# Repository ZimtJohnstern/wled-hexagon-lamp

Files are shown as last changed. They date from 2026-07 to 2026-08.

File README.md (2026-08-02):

# WLED Hexagon Project

*[Deutsche Version](README.de.md)*

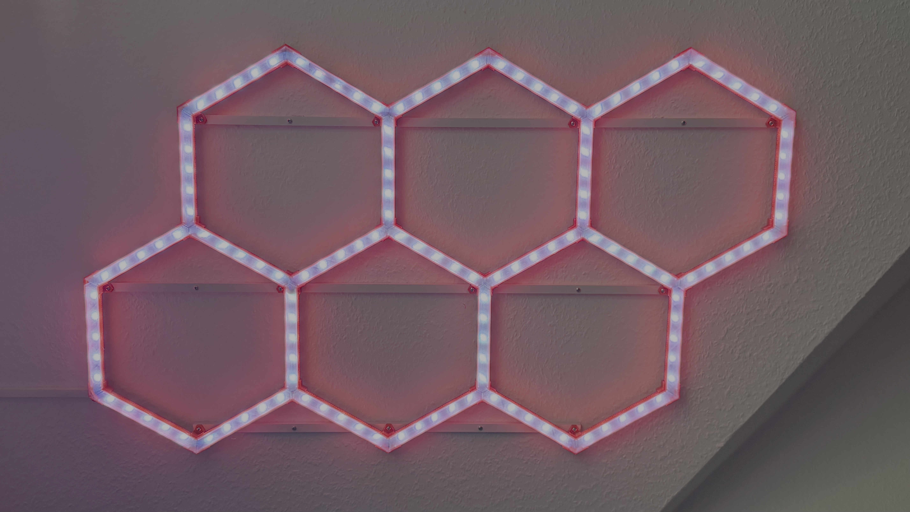
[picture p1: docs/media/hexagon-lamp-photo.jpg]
Finished lamp


6 clip-together LED hexagons (frame design: [Hexagon LED Lamp by NickiDotDK, Printables](https://www.printables.com/model/1063657), CC BY-NC 4.0), driven by WLED on an ESP32 with WS2801 strips and a custom PCB.

**→ Full build guide including video: [BUILD_GUIDE.md](BUILD_GUIDE.md)**

## Hardware overview

| Component | Value/Type |
|---|---|
| MCU | ESP32-WROOM-32, 30-pin devboard |
| LEDs | WS2801, 135 LEDs total, 6 hexagons |
| Power supply | 5 V / 10 A |
| Level buffer | IC1: SN74AHCT125N |
| Data pin (ESP32) | GPIO 23 |
| Clock pin (ESP32) | GPIO 18 |

Details, BOM and wiring: [`docs/hardware.md`](docs/hardware.md) · WLED configuration: [`docs/wled-config.md`](docs/wled-config.md)

*(Note: `docs/hardware.md` and `docs/wled-config.md` are currently German-only. Ask/open an issue if you'd like an English translation.)*

## Repo structure

```
WLED_Hexagone_Project/
├── README.md / README.de.md
├── BUILD_GUIDE.md / BUILD_GUIDE.de.md
├── LICENSE.md                   # CC BY-NC-SA 4.0 for board/enclosure/firmware config
├── .gitignore
├── docs/
│   ├── hardware.md              # BOM, pinout, wiring (German)
│   ├── wled-config.md           # WLED setup, verified config values, LED mapping (German)
│   └── media/
│       ├── hexagon-lamp-photo.jpg
│       ├── clip.mov
│       └── ledmap-reference-jakepeters.png
├── hardware/
│   ├── pcb/
│   │   ├── schaltplan.pdf       # schematic
│   │   ├── ESP32_WLED_WS2801.step
│   │   ├── BOM.txt
│   │   └── CAMOutputs/           # Gerber, drill, assembly (manufacturing data)
│   └── enclosure/
│       ├── WLED_Case_5V10A_ESP32.step
│       ├── Top.3mf / Bottom.3mf / Clamp_in.3mf / Clamp_out.3mf
│       └── Top.stl / Bottom.stl / Clamp_in.stl / Clamp_out.stl
├── model-source/
│   ├── LICENSE-model.md         # CC BY-NC 4.0 notice for the hexagon STL/STEP model
│   └── hexagon-led-lamp.pdf     # Original Printables product page export
├── printables/                  # Printables.com submission package
└── firmware/
    ├── ledmap.json
    ├── wled_cfg_WLED.json
    └── wled_presets_WLED.json
```

## WLED fork

This project uses a fork of [wled/WLED](https://github.com/wled/WLED) (official upstream, MIT license). Include the fork as a **git submodule** or a **separate repo** — see [`docs/wled-config.md`](docs/wled-config.md) for the recommended command.

## License

- Hexagon 3D model: [NickiDotDK](https://www.printables.com/model/1063657), CC BY-NC 4.0 — see `model-source/LICENSE-model.md`
- PCB, enclosure, firmware configuration of this project: **CC BY-NC-SA 4.0** — see [`LICENSE.md`](LICENSE.md). Commercial resale of replicas is not permitted; private builds and non-commercial sharing with attribution are welcome.

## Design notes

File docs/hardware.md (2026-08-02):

# Hardware

## Stückliste (BOM)

Quelle: Export aus Fusion Electronics/EAGLE, Projekt `ESP32_WLED_WS2801` (`hardware/pcb/BOM.txt`).
## Stückliste / Bill of Materials (BOM)

Die folgende Tabelle listet die verwendeten Elektronikkomponenten für das Projekt auf. Die Links führen direkt zu den von mir verwendeten Artikeln auf AliExpress:

| Ref | Bauteil | Menge | Wert / Typ | Package / Info | Link |
| :--- | :--- | :---: | :--- | :--- | :--- |
| **—** | **Microcontroller** | 1 | ESP32 DevBoard | 30-Pin Version | [Auf AliExpress ansehen](https://s.click.aliexpress.com/e/_c32ZkRiR)* |
| **—** | **LED-Streifen** | 1 | WS2801 (5 Meter) | Digital steuerbarer LED-Strip (Data & CLK) | [Auf AliExpress ansehen](https://s.click.aliexpress.com/e/_c3UGIH2X)* |
| **IC1** | **Quad-Bus-Buffer** | 1 | SN74AHCT125N | DIL14 (Pegelwandler für Datensignal) | [Auf AliExpress ansehen](https://s.click.aliexpress.com/e/_c4MjYV6J)* |
| **F1** | **Sicherungshalter** | 1 | 250 V / 10 A | Keystone 4527 / Inkl. Sicherung | [Auf AliExpress ansehen](https://s.click.aliexpress.com/e/_c4r8BMD1)* |
| **C1, C2** | **Elko (Kondensator)** | 2 | 470 µF | CAPPRD200W80D500H1100B (Aus Kit) | [Auf AliExpress ansehen](https://s.click.aliexpress.com/e/_c39kk2Jl)* |
| **C3** | **Kondensator** | 1 | 100 nF | C050-025X075 (Aus Metallkondensator-Kit) | [Auf AliExpress ansehen](https://s.click.aliexpress.com/e/_c3iZH0cB)* |
| **R1, R2** | **Widerstand** | 2 | 100 Ω | 0207/10 | [Auf AliExpress ansehen](https://s.click.aliexpress.com/e/_c3YJjZPD)* |
| **U$1** | **Klemmleiste 2-polig** | 1 | 2828XX-2282837-2 | Stromversorgung In: V+ / V- vom Netzteil | [Auf AliExpress ansehen](https://s.click.aliexpress.com/e/_c3zC1WLl)* |
| **U$2** | **Klemmleiste 4-polig** | 1 | 2828XX-4282837-4 | Ausgang zu WS2801: V+, Data, CLK, V- | [Auf AliExpress ansehen](https://s.click.aliexpress.com/e/_c3zC1WLl)* |
| **—** | **Netzteil** | 1 | 5V / 10A | Stromversorgung für das Gesamtsystem | [Auf AliExpress ansehen](https://s.click.aliexpress.com/e/_c4Lgpqx9)* |
| **-** | Filament | — | Kingroon PETG (für das Gehäuse) | Grau / Wunschfarbe | [Auf AliExpress ansehen](https://s.click.aliexpress.com/e/_c3n4955V)* |
---

### 📢 Transparenzhinweis & Support
Die mit einem Sternchen (`*`) gekennzeichneten Produktlinks sind sogenannte **Affiliate-Links**. Wenn du über diese Links auf AliExpress einkaufst, erhalte ich eine kleine Provision vom Händler. Für dich entstehen dabei **absolut keine Mehrkosten**. Du unterstützt damit direkt die Weiterentwicklung und Pflege dieses Open-Source-Projekts. Vielen Dank!

## Pinbelegung ESP32

| Funktion | GPIO |
|---|---|
| WS2801 Data | 23 |
| WS2801 Clock | 18 |

## Verdrahtungshinweise

**Projektspezifisch (verifiziert):** U$2 liefert V+ (5V), Data und CLK für den WS2801-Strip. Beim Verdrahten der 6 Hexagone gilt: **Anfangspunkt und Endpunkt der Kette müssen beide mit 5V gespeist werden**, um Spannungsabfall über die gesamte Kette zu vermeiden — nicht nur am Anfang einspeisen.

**Zum Vergleich, Original-Community-Modell (NickiDotDK, andere Spannungslage):** Dessen Bauanleitung nutzt 12V-LED-Strips (nicht adressierbar, kein WS2801) und empfiehlt dort, bei 4 Hexagonen 3 einzelne Strips separat mit Strom zu speisen ("power infuse"). Das ist ein anderer LED-Typ mit anderer Spannung als in diesem Projekt (WS2801, 5V) — als Hintergrund erwähnt, aber nicht direkt auf dieses Setup übertragbar.

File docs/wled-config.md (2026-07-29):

# WLED-Setup

## Fork einbinden

Zwei Optionen, je nachdem ob ihr eigenen Code in WLED ändern wollt oder nur konfiguriert:

**Option A — WLED als git submodule (empfohlen, wenn ihr WLED-Quellcode selbst anpasst):**
```bash
cd WLED_Hexagone_Project
git submodule add https://github.com/<euer-fork>/WLED.git firmware/WLED
git commit -m "Add WLED fork as submodule"
```

**Option B — nur Verweis/Fork-Link im Doc, kein Submodule** (ausreichend, wenn ihr WLED nur über die Web-UI konfiguriert, ohne Quellcode-Änderungen).

## Verifizierte Hardware-Konfiguration

Aus `firmware/wled_cfg_WLED.json` (Gerätename: `WLED_Buero`), Werte gegen den WLED-Quellcode (`wled00/const.h`) geprüft:

| Feld | Wert | Bedeutung |
|---|---|---|
| `type` | 50 | `TYPE_WS2801` — bestätigt korrekt |
| `pin` | [23, 18] | Data = GPIO 23, Clock = GPIO 18 |
| `order` | 2 | `COL_ORDER_BRG` — Farbkanalreihenfolge Blau-Rot-Grün |
| `total` | 135 | Gesamtzahl LEDs (nicht 180 — siehe Korrektur unten) |
| `ledma` | 60 | max. mA-Limit pro LED (60mA) |
| `maxpwr` | 8000 | Strombegrenzung gesamt: 8000 mA |
| `fps` | 42 | |

**Korrektur ggü. erster Schätzung:** 135 LEDs gesamt, nicht 6×6×5=180. Aus den Presets ersichtlich: Segment "Aussen" = 90 LEDs (Index 0–90), Segment "Innen" = 45 LEDs (Index 90–135). Bei der Honeycomb-Anordnung (gemeinsame Kanten zwischen benachbarten Hexagonen) ist die tatsächliche Seitenzahl niedriger als bei 6 vollständig getrennten Hexagonen.

## LED-Mapping

`firmware/ledmap.json` enthält die physische Pixel-Reihenfolge (`map`-Array, 135 Einträge, Index 0–134) — vermutlich zur Kompensation der Verkabelungsreihenfolge, damit Segmente/Effekte in der WLED-UI der visuellen Anordnung der Hexagone entsprechen statt der physischen Kabelreihenfolge.

`docs/media/ledmap-reference-jakepeters.png` ist ein Referenzdiagramm mit LED-Nummerierung von **Jake Peters** ("WLED Hexagon Lamp", eigenständiges Projekt/Community-Referenz) — das ist **nicht** derselbe Urheber wie das physische Hexagon-Modell (NickiDotDK, siehe `model-source/`). Beide Namen sollten in der Doku nicht vermischt werden, falls ihr das Repo veröffentlicht: NickiDotDK = 3D-Modell (CC BY-NC 4.0), Jake Peters = LED-Mapping-Referenz (Lizenz unbekannt, hier nicht mitgeliefert, nur als eigenes Foto/Screenshot referenziert).

## Presets

`firmware/wled_presets_WLED.json` enthält 9 gespeicherte Presets (Solid, Chase, Aurora, Candle Multi, Lake, Plasma, Rocktaves, Shimmer, Tetrix), jeweils mit eigenen Effekt-/Palette-Einstellungen pro Segment (Aussen/Innen getrennt ansteuerbar).

## Hardware-Konfiguration in der WLED-Web-UI (zum Nachvollziehen/Neuaufsetzen)

1. Config → LED Preferences
2. LED-Typ: **WS2801 (SPI)**
3. Data-Pin: **23**, Clock-Pin: **18**
4. Farbreihenfolge: **BRG**
5. Anzahl LEDs: **135**
6. Segmente: "Aussen" (0–90), "Innen" (90–135) — siehe Presets für exakte Werte

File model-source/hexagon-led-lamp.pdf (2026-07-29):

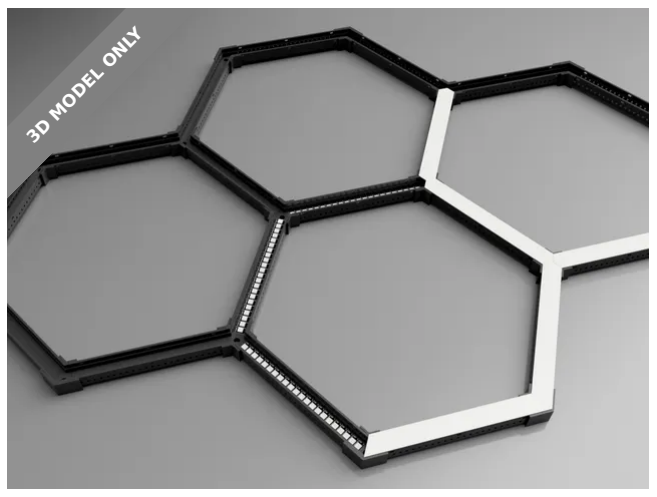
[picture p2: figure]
3D MODEL ONLY

## Summary

Click together hexagon LED lamp.

Household (https://printables.com/model?categoryId=3) > Home Decor (https://printables.com/model?categoryId=44)

Tags: | hexagon | light | lamp | led | ledlight | ledlamp
hexagonled

Click together hexagon LED lamp. Perfect for garage, homegym, workshop or similar. There is room for wiring underneath the individual segments and holes in the corner pieces to feed the wires to the led strips.

I am using 12v natural white led strips from ali with 1200 leds per 5 meters https://www.aliexpress.com/item/1005002355317307.html?spm=a2g0o.order_list.order_list_main.5.7f2279d2mBYwmp (https://www.aliexpress.com/item/1005002355317307.html)

The led strips are pretty bright but could have been a bit brighter imo.

if anyone know of some good high lumen 12v led strips, please feel free to dm me!

I am using 10x2mm flat aluminum profiles as heatsinks underneath the led strips.

NickiDotDK (https://printables.com/@NickiDotDK_1790933)

## Hexagon LED Lamp

VIEW IN BROWSER (https://printables.com/model/1063657-hexagon-led-lamp)

updated 11. 3. 2025 | published 11. 3. 2025

## Model files

Make sure to either power infuse or run wires that power a limited amount of hexagons. For 4 heagons I run power for 3 individual strips.

I have printed the rails and corners in PLA and the diffusers in PETG.

No support needed.

Infill 15%.

rail-straight.stl

double-joint-with-screw-fixture.stl

tripple-joint-with-screw-fixture.stl

tripple-joint.stl

double-joint.stl

double-joint-with-wire-entry.stl

diffuser-straight-triple-double-right.stl

## License

This work is licensed under a
Creative Commons (4.0 International License)

Attribution-NonCommercial (http://creativecommons.org/licenses/by-nc/4.0/)

✖ | Sharing without ATTRIBUTION
✔ | Remix Culture allowed
✖ | Commercial Use
✖ | Free Cultural Works
✖ | Meets Open Definition

diffuser-straight-tripple-tripple.stl

diffuser-straight-triple-double-left.stl

diffuser-straight-double-double.stl

hexagonled.step

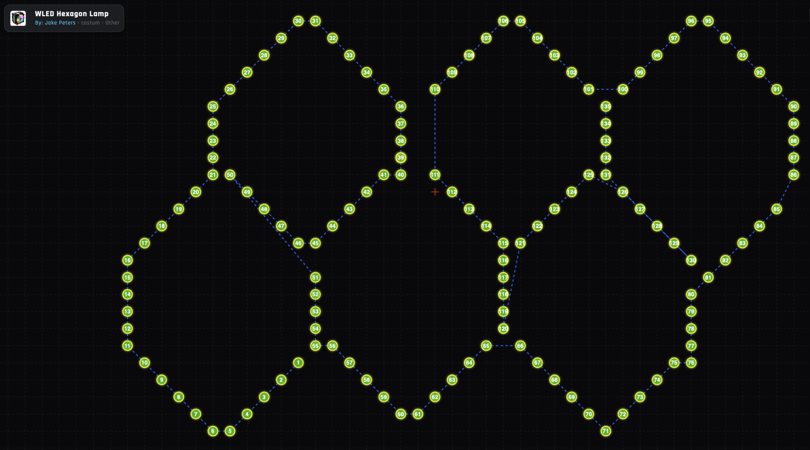
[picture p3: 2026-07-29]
docs/media/ledmap-reference-jakepeters.png

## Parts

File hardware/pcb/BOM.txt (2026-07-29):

Partlist exported from ESP32_WLED_WS2801

Reference Designators Quantity Description                                                   Package                Value            Manufacturer                    Manufacturer Part Number Vendor Vendor Part Number Top/Bottom 
                      1        Board                                                         Board                                                                                                                                 
C1, C2                2        Capacitor Polarised - Generic                                 CAPPRD200W80D500H1100B 470µF                                                                                              Top        
C3                    1        CAPACITOR, European symbol                                    C050-025X075           100nF                                                                                               Top        
F1                    1        FUSE HLDR CARTRIDGE 250V 5A PCB                               4527                   4527             Keystone Electronics            4527                                               Top        
IC1                   1        Quad bus BUFFER, 3-state                                      DIL14                  74125N                                                                                              Top        
JP1, JP2              2        Pin Header                                                    1X15                   PINHD-1X15                                                                                          Top        
R1, R2                2        RESISTOR, European symbol                                     0207/10                100                                                                                                 Top        
U$1                   1        2 Position Wire to Board Terminal Block Horizontal with Board TERMBLK_508-2N         2828XX-2282837-2 TE Connectivity AMP Connectors  282837-2                                           Top        
U$2                   1        4 Position Wire to Board Terminal Block Horizontal with Board TERMBLK_508-4N         2828XX-4282837-4 TE Connectivity AMP Connectors  282837-4                                           Top

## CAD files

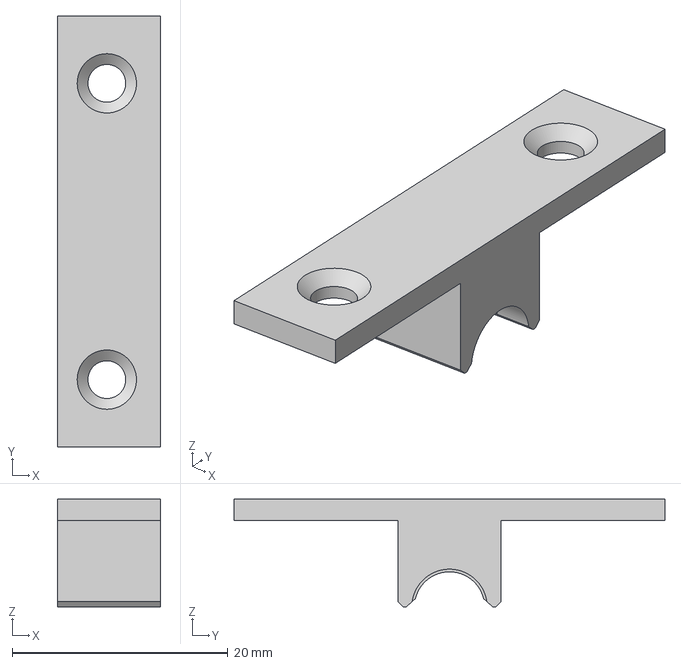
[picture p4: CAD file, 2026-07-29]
hardware/enclosure/Clamp_out.3mf
9.60 x 40.0 x 10.0 mm

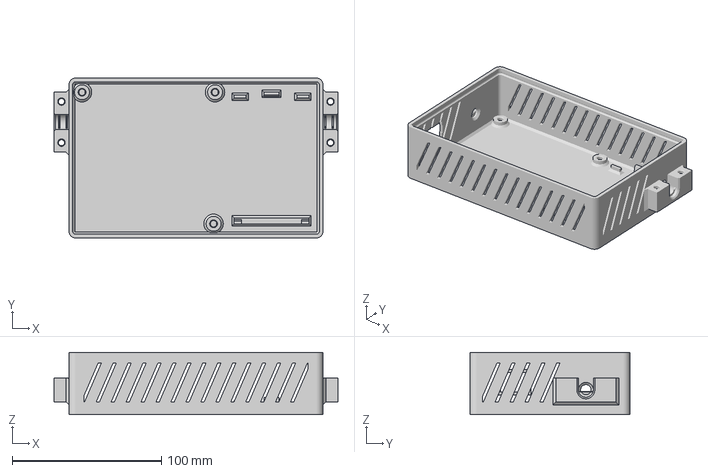
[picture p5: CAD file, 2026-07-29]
printables/Bottom.3mf
190.0 x 107.0 x 41.5 mm

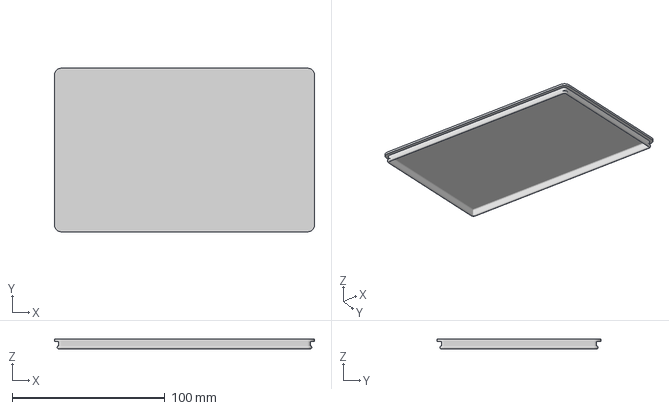
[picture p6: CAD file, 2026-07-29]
hardware/enclosure/Top.3mf
170.0 x 107.0 x 6.50 mm

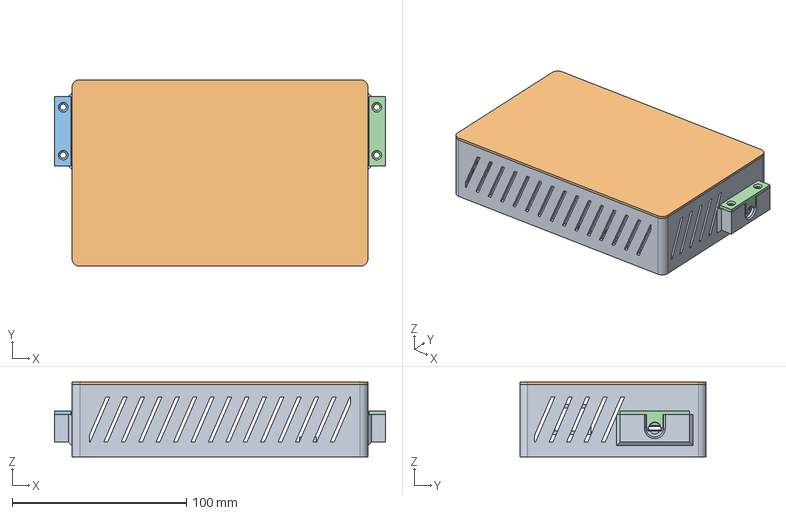
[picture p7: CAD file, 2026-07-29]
hardware/enclosure/WLED_Case_5V10A_ESP32.step
190.0 x 107.0 x 43.0 mm

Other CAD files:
hardware/enclosure/Clamp_in.3mf
printables/Clamp_in.3mf
hardware/enclosure/Bottom.stl
hardware/enclosure/Clamp_in.stl
hardware/enclosure/Clamp_out.stl
hardware/enclosure/Top.stl
printables/Bottom.stl
printables/Clamp_in.stl
printables/Clamp_out.stl
printables/Top.stl

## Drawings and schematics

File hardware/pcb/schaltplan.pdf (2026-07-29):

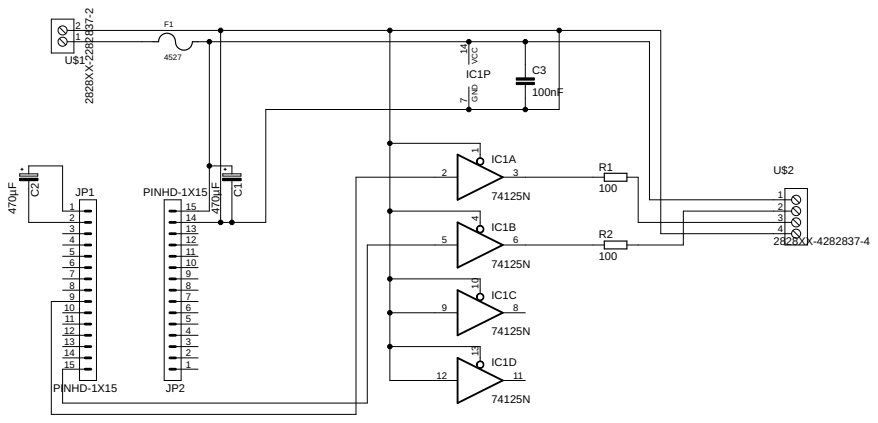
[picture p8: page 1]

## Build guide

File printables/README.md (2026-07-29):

# Printables.com — Submission Package

This project isn't a modification of the hexagon frame geometry itself — it's a **controller/case add-on** (custom PCB + WLED firmware + power enclosure) that complements NickiDotDK's original hexagon model. Two ways to list it, pick based on how much you want to maintain there:

## Option A — Quick: post as a "Make" of the original model

Go to [NickiDotDK's Hexagon LED Lamp page](https://www.printables.com/model/1063657) → **"I Made This"** → upload photo/video, short text mentioning your custom WS2801/ESP32/WLED controller. Fast, low-maintenance, automatically credited and linked to the original — but no separate page for your PCB/case files.

## Option B — Own listing: new model, explicitly linked as related work

Create a **new model page**, upload only the files that are actually yours (`printables/*.3mf` — the enclosure), and reference the hexagon frames as a required companion print. This gives your PCB/enclosure its own visibility and license.

### Files to upload

From `printables/`:
- `Top.3mf` / `Top.stl`
- `Bottom.3mf` / `Bottom.stl`
- `Clamp_in.3mf` / `Clamp_in.stl`
- `Clamp_out.3mf` / `Clamp_out.stl`

Both formats are included — STL is often preferred on Printables for broader slicer compatibility, 3MF preserves any print settings/color info from Fusion 360. Upload both, or just STL if you want to keep the listing lean.

Do **not** re-upload the hexagon frame STLs — link to NickiDotDK's page instead (required by their CC BY-NC 4.0 attribution clause, and it's their work, not yours to redistribute as your own listing).

### Suggested title

**WLED Hexagon Lamp — ESP32/WS2801 Controller & Enclosure**

### Suggested summary (short)

Custom ESP32 + WS2801 controller PCB and 5V/10A power enclosure for NickiDotDK's Hexagon LED Lamp, running WLED.

### Suggested description (long, ready to paste)

> This is a controller/enclosure add-on for [NickiDotDK's Hexagon LED Lamp](https://www.printables.com/model/1063657) — **print that model first**, this listing only covers the electronics enclosure.
>
> Included:
> - 3D-printable enclosure (Top/Bottom/Clamp_in/Clamp_out) for a custom PCB + 5V/10A power supply
> - Full open-source repo with schematic, Gerber files, BOM, and WLED configuration: **[link your GitHub repo here]**
>
> Hardware: ESP32-WROOM-32 (30-pin), WS2801 LED strips (135 LEDs across 6 hexagons), 74AHCT125 level buffer, 5V/10A PSU.
>
> Full build guide (BOM, wiring, WLED setup, troubleshooting): see the GitHub repo linked above.
>
> **Credit:** hexagon frame design by NickiDotDK, licensed CC BY-NC 4.0. This controller/enclosure add-on is not affiliated with the original creator.

### Print settings (enclosure)

- Material: PLA (matches rails/corners of the base hexagon model) or PETG for extra heat tolerance near the power supply
- Infill: 15–20% (higher than the base model recommended, since it houses a mains-adjacent PSU)
- Supports: check per part in your slicer — not verified here, test print first

### License on Printables

Printables lets you pick a license per upload. To stay consistent with this project's GitHub license, select **CC BY-NC-SA 4.0** if offered, or the closest equivalent (CC BY-NC if SA isn't available) — matches [`LICENSE.md`](../LICENSE.md) in the repo.

### Tags

`wled` `esp32` `ws2801` `led` `hexagon` `honeycomb` `led-lamp` `addressable-led` `home-decor` `smart-lighting`

---

## Before you publish — checklist

- [ ] Link to NickiDotDK's original model is visible and prominent (attribution requirement of their CC BY-NC 4.0 license)
- [ ] GitHub repo link added to the description once pushed
- [ ] License selected on Printables matches `LICENSE.md`
- [ ] Photo/video uploaded (same cleaned files as `docs/media/`)

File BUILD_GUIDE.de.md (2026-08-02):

# WLED Hexagon Lamp — Bauanleitung

*[English version](BUILD_GUIDE.md)*

Eine modulare 6-Hexagon-LED-Wandlampe auf Basis von [WLED](https://github.com/wled/WLED), WS2801-LED-Strips und einer selbstentwickelten ESP32-Platine.

Fertige Lampe

<video src="docs/media/clip.mov" controls width="600">
  Dein Browser/Client kann das Video nicht direkt abspielen — <a href="docs/media/clip.mov">hier herunterladen</a>.
</video>

*(Falls das Video in deinem Markdown-Viewer nicht abspielt: Datei liegt unter `docs/media/clip.mov`, GitHub spielt sie im Repo-Viewer direkt ab.)*

---

## Was das ist

6 druckbare LED-Hexagone, honeycomb-artig zusammengesteckt, mit WS2801-Strips bestückt und über eine eigene ESP32-Platine mit WLED angesteuert. Zwei unabhängige Segmente ("Aussen"/"Innen") lassen sich getrennt mit Effekten/Farben belegen.

## Voraussetzungen

- 3D-Drucker (PLA für Rahmen/Ecken, PETG für Diffusoren empfohlen)
- Löterfahrung für die Platine (THT-Bauteile, keine SMD)
- Grundkenntnisse ESP32/Arduino-Umgebung bzw. Web-Flashen von WLED
- PCB-Fertigung extern (Gerber-Files liegen bei) oder eigene Lötplatine nach Schaltplan

---

## 1. Stückliste (BOM)

Vollständige BOM: [`hardware/pcb/BOM.txt`](hardware/pcb/BOM.txt)

| Ref | Bauteil | Menge | Wert / Typ |  Link |
| :--- | :--- | :---: | :--- | :--- |
| **—** | **Microcontroller** | 1 | ESP32 DevBoard | [Auf AliExpress ansehen](https://s.click.aliexpress.com/e/_c32ZkRiR)* |
| **—** | **LED-Streifen** | 1 | WS2801 (5 Meter) | [Auf AliExpress ansehen](https://s.click.aliexpress.com/e/_c3UGIH2X)* |
| **IC1** | **Quad-Bus-Buffer** | 1 | SN74AHCT125N | [Auf AliExpress ansehen](https://s.click.aliexpress.com/e/_c4MjYV6J)* |
| **F1** | **Sicherungshalter** | 1 | 250 V / 10 A | [Auf AliExpress ansehen](https://s.click.aliexpress.com/e/_c4r8BMD1)* |
| **C1, C2** | **Elko (Kondensator)** | 2 | 470 µF | [Auf AliExpress ansehen](https://s.click.aliexpress.com/e/_c39kk2Jl)* |
| **C3** | **Kondensator** | 1 | 100 nF | [Auf AliExpress ansehen](https://s.click.aliexpress.com/e/_c3iZH0cB)* |
| **R1, R2** | **Widerstand** | 2 | 100 Ω | [Auf AliExpress ansehen](https://s.click.aliexpress.com/e/_c3YJjZPD)* |
| **U$1** | **Klemmleiste 2-polig** | 1 | 2828XX-2282837-2 | [Auf AliExpress ansehen](https://s.click.aliexpress.com/e/_c3zC1WLl)* |
| **U$2** | **Klemmleiste 4-polig** | 1 | 2828XX-4282837-4 | [Auf AliExpress ansehen](https://s.click.aliexpress.com/e/_c3zC1WLl)* |
| **—** | **Netzteil** | 1 | 5V / 10A | [Auf AliExpress ansehen](https://s.click.aliexpress.com/e/_c4Lgpqx9)* |
| **-** | Filament | — | Kingroon PETG (für das Gehäuse) | [Auf AliExpress ansehen](https://s.click.aliexpress.com/e/_c3n4955V)* 

### 📢 Transparenzhinweis & Support
Die mit einem Sternchen (`*`) gekennzeichneten Produktlinks sind sogenannte **Affiliate-Links**. Wenn du über diese Links auf AliExpress einkaufst, erhalte ich eine kleine Provision vom Händler. Für dich entstehen dabei **absolut keine Mehrkosten**. Du unterstützt damit direkt die Weiterentwicklung und Pflege dieses Open-Source-Projekts. Vielen Dank!

**Hinweis IC1 (SN74AHCT125N):** HCT-Variante mit TTL-kompatiblem Eingang (verträgt 3,3V-Logik vom ESP32) und vollem 5V-CMOS-Ausgangshub — funktioniert als Pegelwandler zwischen ESP32 und WS2801. Auf dem Bauteil selbst bzw. im Handel teils nur generisch als "74125" gelistet — auf die **AHCT**-Variante achten, sonst kein sauberer High-Pegel am Strip.

---

## 2. Platine

- Schaltplan: [`hardware/pcb/schaltplan.pdf`](hardware/pcb/schaltplan.pdf)
- 3D-Modell (STEP): [`hardware/pcb/ESP32_WLED_WS2801.step`](hardware/pcb/ESP32_WLED_WS2801.step)
- Fertigungsdaten (Gerber/Drill/Assembly, fertig für JLCPCB/PCBWay o. ä.): [`hardware/pcb/CAMOutputs/`](hardware/pcb/CAMOutputs/)

**Bestückungshinweis:** JP1/JP2 sind die beiden 15-poligen Buchsenleisten für das ESP32-Devboard (30 Pin gesamt). U$1 nimmt die 5V-Versorgung vom Netzteil auf, U$2 gibt V+, Data, CLK und V− an den ersten WS2801-Strip weiter.

---

## 3. Gehäuse

3D-Druckdateien für das Netzteil-/Platinengehäuse:

- STEP (falls ihr's anpassen wollt): [`hardware/enclosure/WLED_Case_5V10A_ESP32.step`](hardware/enclosure/WLED_Case_5V10A_ESP32.step)
- Druckfertige 3MF-Dateien: [`Top.3mf`](hardware/enclosure/Top.3mf), [`Bottom.3mf`](hardware/enclosure/Bottom.3mf), [`Clamp_in.3mf`](hardware/enclosure/Clamp_in.3mf), [`Clamp_out.3mf`](hardware/enclosure/Clamp_out.3mf)
- Dieselben Teile als STL: [`Top.stl`](hardware/enclosure/Top.stl), [`Bottom.stl`](hardware/enclosure/Bottom.stl), [`Clamp_in.stl`](hardware/enclosure/Clamp_in.stl), [`Clamp_out.stl`](hardware/enclosure/Clamp_out.stl)

---

## 4. Hexagon-Rahmen drucken

Das eigentliche Hexagon-Modell stammt **nicht** aus diesem Projekt, sondern von [NickiDotDK auf Printables](https://www.printables.com/model/1063657) (Original: [`model-source/hexagon-led-lamp.pdf`](model-source/hexagon-led-lamp.pdf)).

- Rails/Ecken: PLA, 15% Infill, kein Support nötig
- Diffusoren: PETG
- LED-Strips: WS2801, 5 V, 5 LEDs pro Seite, aufgeklebt auf 10×2mm Aluprofile als Kühlkörper

⚠️ **Lizenz beachten:** Das Hexagon-Modell steht unter **CC BY-NC 4.0** — Namensnennung (NickiDotDK) Pflicht, keine kommerzielle Nutzung. Details: [`model-source/LICENSE-model.md`](model-source/LICENSE-model.md)

---

## 5. Verkabelung

- ESP32 Data → GPIO 23, Clock → GPIO 18 (über IC1 gepuffert)
- Nicht alle 6 Hexagone in einer Kette durchverkabeln — Spannungsabfall vermeiden. **Wichtig:** Sowohl Anfangs- als auch Endpunkt der LED-Kette müssen mit 5V gespeist werden (U$2 liefert V+, Data, CLK), nicht nur der Startpunkt — sonst fällt die Spannung zum Kettenende hin ab und die letzten LEDs werden dunkler/farbverfälscht.
- Details: [`docs/hardware.md`](docs/hardware.md)

---

## 6. WLED flashen & konfigurieren

1. WLED (Standard-Release oder eigenen Fork) auf den ESP32 flashen.
2. Web-UI → **Config → LED Preferences**:
   - LED-Typ: **WS2801 (SPI)**
   - Data-Pin: **23**, Clock-Pin: **18**
   - Farbreihenfolge: **BRG**
   - Anzahl LEDs: **135**
3. Segmente anlegen: "Aussen" (0–90), "Innen" (90–135)
4. Optional: fertige Konfiguration direkt importieren — [`firmware/wled_cfg_WLED.json`](firmware/wled_cfg_WLED.json) und [`firmware/wled_presets_WLED.json`](firmware/wled_presets_WLED.json) über WLED → Config → File Editor hochladen.

Details/Hintergrund zu den Werten: [`docs/wled-config.md`](docs/wled-config.md)

---

## 7. LED-Mapping

Damit Effekte der visuellen Hexagon-Anordnung folgen (statt der physischen Verkabelungsreihenfolge), liegt eine `ledmap.json` bei: [`firmware/ledmap.json`](firmware/ledmap.json). Unter WLED → Config → LED Preferences → "Ledmap" hochladen.

Referenzdiagramm zur Pixel-Nummerierung (Community-Ressource von Jake Peters, unabhängig vom Hexagon-Modell selbst): [`docs/media/ledmap-reference-jakepeters.png`](docs/media/ledmap-reference-jakepeters.png)

---

## 8. Presets

9 vorkonfigurierte Presets liegen bei (Solid, Chase, Aurora, Candle Multi, Lake, Plasma, Rocktaves, Shimmer, Tetrix), je mit getrennten Effekten für "Aussen"/"Innen": [`firmware/wled_presets_WLED.json`](firmware/wled_presets_WLED.json)

---

## Troubleshooting

- **Falsche Farben:** Farbreihenfolge in WLED prüfen (hier: BRG, nicht der Default GRB).
- **Kein Signal/Flackern:** IC1 muss die **74AHCT125**-Variante sein, nicht der einfache 74125 (fehlender sauberer 5V-High-Pegel).
- **Spannungsabfall am Ende der Kette:** Anfangs- und Endpunkt der Verkabelung beide mit 5V speisen (nicht nur den Anfang), ggf. Kabelquerschnitt erhöhen.

---

## Lizenz

- Hexagon-3D-Modell: [NickiDotDK](https://www.printables.com/model/1063657), CC BY-NC 4.0 — keine kommerzielle Nutzung, Namensnennung Pflicht
- Platine, Gehäuse, Firmware-Konfiguration dieses Projekts: **CC BY-NC-SA 4.0**, siehe [`LICENSE.md`](LICENSE.md) — kommerzieller Nachbau/Verkauf ausdrücklich nicht gestattet, privater Nachbau und nicht-kommerzielle Weitergabe mit Namensnennung erwünscht

## Credits

- Hexagon-3D-Modell: [NickiDotDK](https://www.printables.com/model/1063657)
- LED-Mapping-Referenzdiagramm: Jake Peters (Community-Ressource, WLED Hexagon Lamp)
- WLED-Firmware: [wled/WLED](https://github.com/wled/WLED) (MIT-Lizenz)
- Platine, Gehäuse, Firmware-Konfiguration: dieses Projekt

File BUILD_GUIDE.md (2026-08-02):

# WLED Hexagon Lamp — Build Guide

*[Deutsche Version](BUILD_GUIDE.de.md)*

A modular 6-hexagon LED wall lamp based on [WLED](https://github.com/wled/WLED), WS2801 LED strips, and a custom ESP32 PCB.

Finished lamp

<video src="docs/media/clip.mov" controls width="600">
  Your viewer can't play the video directly — <a href="docs/media/clip.mov">download it here</a>.
</video>

*(If the video doesn't play in your markdown viewer: it's at `docs/media/clip.mov` — GitHub plays it inline in the repo file viewer.)*

---

## What this is

6 printable LED hexagons, clicked together honeycomb-style, fitted with WS2801 strips and driven by a custom ESP32 PCB running WLED. Two independent segments ("Outer"/"Inner") can be driven with separate effects/colors.

## Prerequisites

- 3D printer (PLA for frame/corners, PETG for diffusers recommended)
- Soldering experience for the PCB (through-hole parts, no SMD)
- Basic ESP32/Arduino environment knowledge, or comfort flashing WLED via the web installer
- External PCB manufacturing (Gerber files included) or hand-soldering from the schematic

---

## 1. Bill of Materials (BOM)

Full BOM: [`hardware/pcb/BOM.txt`](hardware/pcb/BOM.txt)

| Ref | Component | Qty | Value / Type | Link |
| :--- | :--- | :---: | :--- | :--- |
| **—** | **Microcontroller** | 1 | ESP32 DevBoard | [View on AliExpress](https://s.click.aliexpress.com/e/_c32ZkRiR)* |
| **—** | **LED Strip** | 1 | WS2801 (5 Meters) | [View on AliExpress](https://s.click.aliexpress.com/e/_c3UGIH2X)* |
| **IC1** | **Quad Bus Buffer** | 1 | SN74AHCT125N | [View on AliExpress](https://s.click.aliexpress.com/e/_c4MjYV6J)* |
| **F1** | **Fuse Holder** | 1 | 250 V / 10 A | [View on AliExpress](https://s.click.aliexpress.com/e/_c4r8BMD1)* |
| **C1, C2** | **Electrolytic Cap** | 2 | 470 µF | [View on AliExpress](https://s.click.aliexpress.com/e/_c39kk2Jl)* |
| **C3** | **Capacitor** | 1 | 100 nF | [View on AliExpress](https://s.click.aliexpress.com/e/_c3iZH0cB)* |
| **R1, R2** | **Resistor** | 2 | 100 Ω | [View on AliExpress](https://s.click.aliexpress.com/e/_c3YJjZPD)* |
| **U$1** | **Terminal Block 2-pin** | 1 | 2828XX-2282837-2 | [View on AliExpress](https://s.click.aliexpress.com/e/_c3zC1WLl)* |
| **U$2** | **Terminal Block 4-pin** | 1 | 2828XX-4282837-4 | [View on AliExpress](https://s.click.aliexpress.com/e/_c3zC1WLl)* |
| **—** | **Power Supply** | 1 | 5V / 10A | [View on AliExpress](https://s.click.aliexpress.com/e/_c4Lgpqx9)* |
| **—** | **Filament** | — | Kingroon PETG (for enclosure) | [View on AliExpress](https://s.click.aliexpress.com/e/_c3n4955V)* |

---

## 📢 Affiliate Disclosure & Support

Product links marked with an asterisk (*) are affiliate links. If you purchase items through these links on AliExpress, I will receive a small commission from the seller. This comes at absolutely no extra cost to you. By using these links, you directly support the further development and maintenance of this open-source project. Thank you for your support!

---

## 2. PCB

- Schematic: [`hardware/pcb/schaltplan.pdf`](hardware/pcb/schaltplan.pdf)
- 3D model (STEP): [`hardware/pcb/ESP32_WLED_WS2801.step`](hardware/pcb/ESP32_WLED_WS2801.step)
- Manufacturing data (Gerber/drill/assembly, ready for JLCPCB/PCBWay etc.): [`hardware/pcb/CAMOutputs/`](hardware/pcb/CAMOutputs/)

**Assembly note:** JP1/JP2 are the two 15-pin sockets for the ESP32 devboard (30 pins total). U$1 takes the 5V supply from the power supply, U$2 outputs V+, Data, CLK and V− to the first WS2801 strip.

---

## 3. Enclosure

3D-print files for the power supply/PCB enclosure:

- STEP (if you want to modify it): [`hardware/enclosure/WLED_Case_5V10A_ESP32.step`](hardware/enclosure/WLED_Case_5V10A_ESP32.step)
- Ready-to-print 3MF files: [`Top.3mf`](hardware/enclosure/Top.3mf), [`Bottom.3mf`](hardware/enclosure/Bottom.3mf), [`Clamp_in.3mf`](hardware/enclosure/Clamp_in.3mf), [`Clamp_out.3mf`](hardware/enclosure/Clamp_out.3mf)
- Same parts as STL: [`Top.stl`](hardware/enclosure/Top.stl), [`Bottom.stl`](hardware/enclosure/Bottom.stl), [`Clamp_in.stl`](hardware/enclosure/Clamp_in.stl), [`Clamp_out.stl`](hardware/enclosure/Clamp_out.stl)

---

## 4. Print the hexagon frames

The hexagon frame model itself is **not** part of this project — it's from [NickiDotDK on Printables](https://www.printables.com/model/1063657) (original page saved as [`model-source/hexagon-led-lamp.pdf`](model-source/hexagon-led-lamp.pdf)).

- Rails/corners: PLA, 15% infill, no supports needed
- Diffusers: PETG
- LED strips: WS2801, 5 V, 5 LEDs per side, mounted on 10×2mm aluminum profiles as heatsinks

⚠️ **License:** The hexagon model is **CC BY-NC 4.0** — attribution to NickiDotDK required, no commercial use. Details: [`model-source/LICENSE-model.md`](model-source/LICENSE-model.md)

---

## 5. Wiring

- ESP32 Data → GPIO 23, Clock → GPIO 18 (buffered through IC1)
- Don't wire all 6 hexagons in one long daisy chain — voltage drop. **Important:** both the start and the end of the LED chain need to be fed 5V (U$2 supplies V+, Data, CLK), not just the start — otherwise voltage sags toward the end of the chain and the last LEDs go dim/off-color.
- Details: [`docs/hardware.md`](docs/hardware.md) *(German)*

---

## 6. Flash & configure WLED

1. Flash WLED (stock release or your own fork) onto the ESP32.
2. Web UI → **Config → LED Preferences**:
   - LED type: **WS2801 (SPI)**
   - Data pin: **23**, Clock pin: **18**
   - Color order: **BRG**
   - LED count: **135**
3. Set up segments: "Outer" (0–90), "Inner" (90–135)
4. Optional: import the ready-made config directly — [`firmware/wled_cfg_WLED.json`](firmware/wled_cfg_WLED.json) and [`firmware/wled_presets_WLED.json`](firmware/wled_presets_WLED.json) via WLED → Config → File Editor.

Background on these values: [`docs/wled-config.md`](docs/wled-config.md) *(German)*

---

## 7. LED mapping

So effects follow the visual hexagon layout instead of the physical wiring order, a `ledmap.json` is included: [`firmware/ledmap.json`](firmware/ledmap.json). Upload it under WLED → Config → LED Preferences → "Ledmap".

Reference diagram for pixel numbering (community resource by Jake Peters, independent of the hexagon model itself): [`docs/media/ledmap-reference-jakepeters.png`](docs/media/ledmap-reference-jakepeters.png)

---

## 8. Presets

9 preconfigured presets are included (Solid, Chase, Aurora, Candle Multi, Lake, Plasma, Rocktaves, Shimmer, Tetrix), each with separate effects for "Outer"/"Inner": [`firmware/wled_presets_WLED.json`](firmware/wled_presets_WLED.json)

---

## Troubleshooting

- **Wrong colors:** check the color order in WLED (here: BRG, not the default GRB).
- **No signal/flicker:** IC1 must be the **74AHCT125** variant, not the plain 74125 (no clean 5V high level otherwise).
- **Voltage drop at the end of the chain:** feed both the start and the end of the wiring with 5V, increase wire gauge if needed.

---

## Credits

- Hexagon 3D model: [NickiDotDK](https://www.printables.com/model/1063657), CC BY-NC 4.0 — no commercial use, attribution required
- LED mapping reference diagram: Jake Peters (community resource, WLED Hexagon Lamp)
- WLED firmware: [wled/WLED](https://github.com/wled/WLED) (MIT license)
- PCB, enclosure, firmware configuration: this project

## License

- Hexagon 3D model: [NickiDotDK](https://www.printables.com/model/1063657), CC BY-NC 4.0
- PCB, enclosure, firmware configuration of this project: **CC BY-NC-SA 4.0**, see [`LICENSE.md`](LICENSE.md) — commercial resale of replicas not permitted, private builds and non-commercial sharing with attribution welcome
